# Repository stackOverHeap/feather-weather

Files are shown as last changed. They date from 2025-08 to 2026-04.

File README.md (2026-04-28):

# Feather-Weather
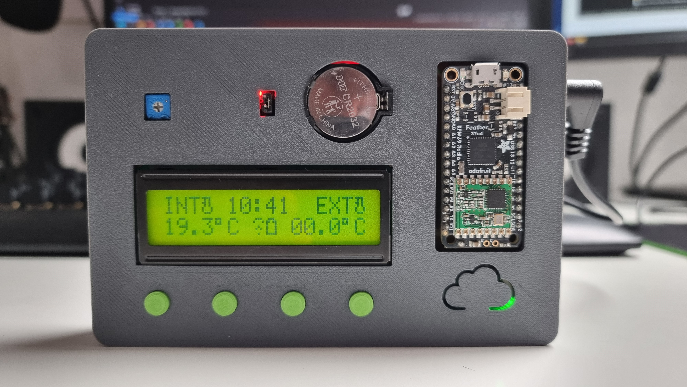
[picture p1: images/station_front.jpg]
The main station

### Qu'est-ce ?
Ce dépot contient le code source d'une **station météorologique** réalisée avec le framework **Arduino**. Elle est divisée en deux unités, équipées chacune de la carte **Adafruit Feather 32u4** Radio, qui travaillent séparément pour fournir des données sur la température et l'humidité ambiante à l'intérieur et à l'extérieur de l'habitacle. La communication entre ces deux unités se fait avec le module **rfm69hcw** sur la fréquence 433 MHz, ce qui permet l'échange de données sur une longue distance.

### Fonctionnalités
- [x] affichage des informations grâce à un écran LCD (16 x 2)
- [x] persistance du comptage de l'heure après coupure de courant (DS3231 RTC)
- [x] affichage de la température et de l'humidité ambiante  (ATH20)
- [x] configuration de l'heure par interface graphique
- [x] navigation dans les menus grâce à quatre bouton poussoires
- [x] voyant indicateur de d'état de batterie et qualité de réception
- [ ] historique des températures (min et max)
- [ ] possibilité de consulter le voltage de la batterie à distance

### TODO
- [x] suppression de la dépendance JSON
- [ ] reduction de l'utilisation de l'i2c pour augmenter la fiabilité du capteur de température (trop de requêtes = surchauffe)
- [ ] suppression de l'utilisation des print-format, trop gourmands pour AVR

## Compilation & Usage
### 1. Cloner le repo git
```bash
git clone https://github.com/stackOverHeap/feather-weather.git
```
### 2. Compiler avec platformIO
```bash
pio run
```
### 3. Flasher sur un micro
flash du code s'éxecutant sur la station interne
```bash
pio run --target upload --environment feather32u4_STATION
```
flash du code s'éxecutant sur la station externe
```bash
pio run --target upload --environment feather32u4_MODULE
```
### 4. Verifier la connexion entre les dispositifs
Pour ceci, s'assurer que l'icone de connexion n'apparaît pas sur l'interface de l'appareil. Un certain temps peut être nécessaire avant la détection du signal.

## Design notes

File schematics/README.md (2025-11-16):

# Project schematics
Theses were made with **KiCad EDA**

## files

- ***station météo externe.zip*** is the main module. It is designed for inside use and display temperature and humidity informations on a LCD screen. It also holds the time and date thanks to the use of a RTC clock.

- ***station météo interne.zip*** is the external module. It is made to be used outside for measuring humidity and temperature data, that it then sends trough radio to the station. A NE555 time is designed to wake the card on 30 secoond interval to reduce power consumption, since it is powered from a single 3.7v ion cell.

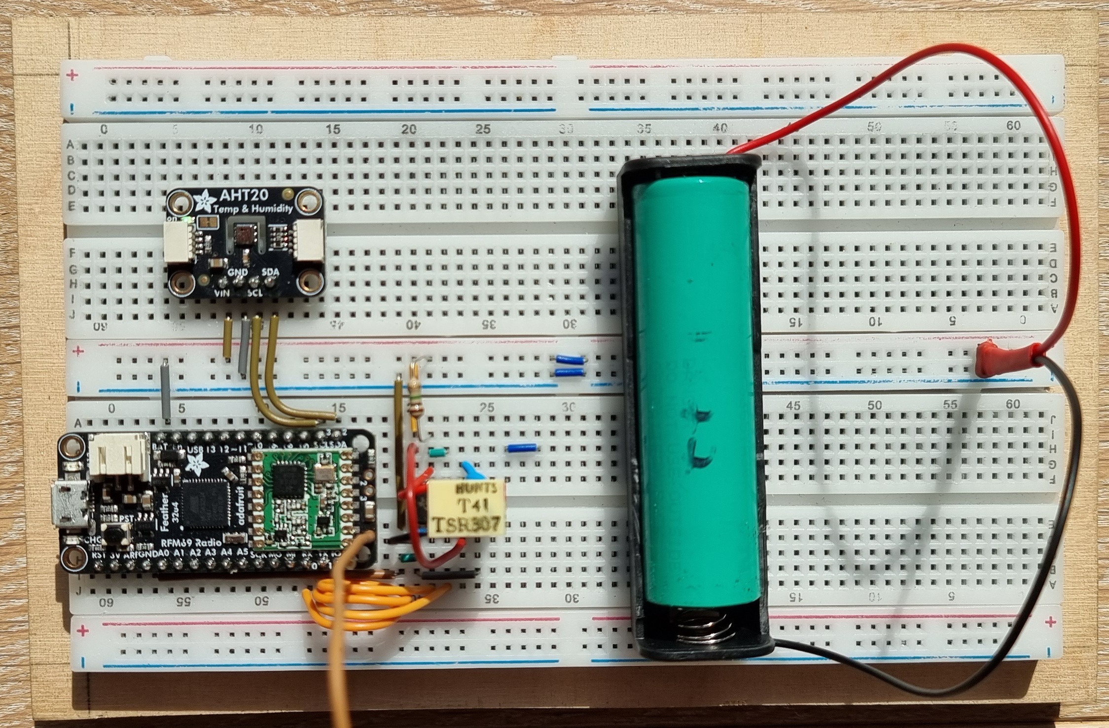
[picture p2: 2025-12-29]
images/module_front.jpg

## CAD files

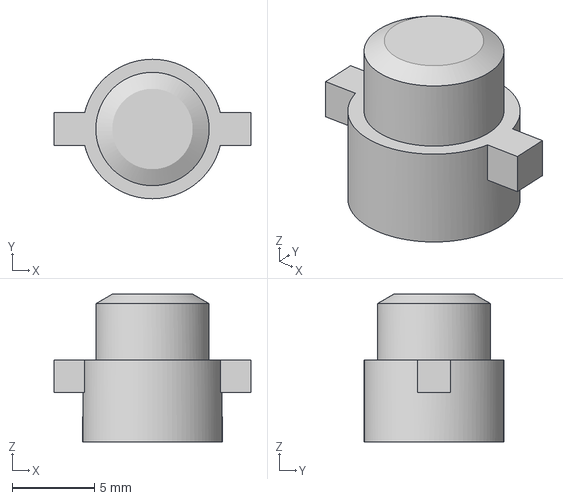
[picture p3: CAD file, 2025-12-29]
3D models/stls/push btn (x4).3mf
12.0 x 8.50 x 9.00 mm

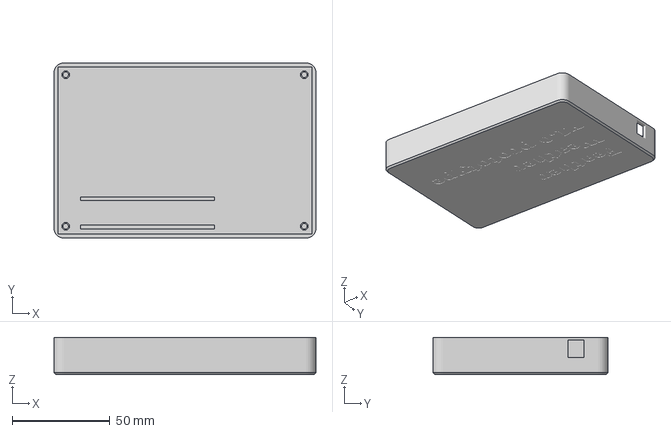
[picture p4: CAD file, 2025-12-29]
3D models/stls/back cover.3mf
134.0 x 89.5 x 19.0 mm

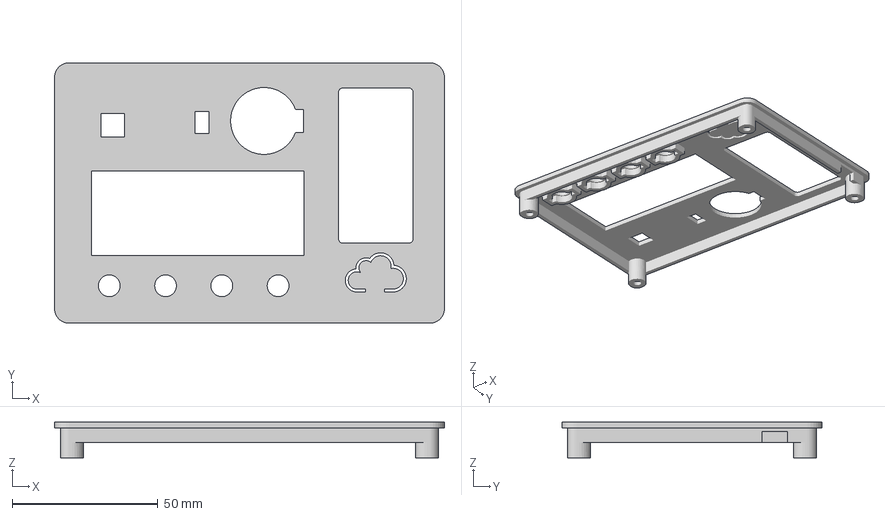
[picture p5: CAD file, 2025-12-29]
3D models/stls/front cover.3mf
134.0 x 89.5 x 12.3 mm

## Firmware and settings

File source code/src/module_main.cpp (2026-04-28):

#ifdef MODULE

#include <Arduino.h>
#include <RH_RF69.h>
#include <Adafruit_AHTX0.h>

#include <avr/wdt.h>
#include <avr/interrupt.h>
#include <avr/power.h>
#include <avr/sleep.h>

#include "radio.h"
#include "data_structure.hpp"

#define VBATPIN A9
#define WKPIN 0 // ne555 out
#define TRGPIN 1 // ne555 trig

#define SLEEP_TIME_S 64
#define SLEEP_CYCLE_COUNT (SLEEP_TIME_S / 8)

#define MIN_BATTERY_VOLTAGE 3.5f

RH_RF69 radio(RFM69_CS, RFM69_INT);
Adafruit_AHTX0 aht;

float vbat = 0;

void update_vbat()
{
  vbat = analogRead(VBATPIN);
  vbat *= 2;
  vbat *= 3.3;
  vbat /= 1024;
}

void wakeup_isr()
{
  digitalWrite(TRGPIN, HIGH);
}

ISR(WDT_vect) {}

void setup() {
  Serial.begin(115200);

  // Init radio
  radio.init();
  radio.setFrequency(RF69_FREQ);
  radio.setTxPower(15, true);  // Adjust based on range / power needs
  radio.setIdleMode(RH_RF69_OPMODE_MODE_SLEEP);

  // Init AHT20 sensor
  aht.begin();

#ifdef NE555
  pinMode(WKPIN, INPUT_PULLUP); 
  // Configure INT2 (D0) to trigger on falling edge
  attachInterrupt(digitalPinToInterrupt(WKPIN), wakeup_isr, FALLING);

  pinMode(TRGPIN, OUTPUT);
  digitalWrite(TRGPIN, HIGH); // prepare for ne555 wakeup pulse

  wdt_disable();
#endif

  power_usart0_disable();
  power_timer1_disable();
  power_timer2_disable();
  power_timer3_disable();
  power_usb_disable();
}

void loop() {  
#ifdef NE555
  EIMSK &= ~(1 << INT2);    // Disable INT2 interrupt
#endif
  // Wake up sensor, get data
  analogRead(VBATPIN); // dummy read
  update_vbat();

  sensors_event_t humidity, temp;
  aht.getEvent(&humidity, &temp);

  paquet_data_structure payload 
  {
    .temperature = temp.temperature,
    .humidity = humidity.relative_humidity,
    .battery_voltage = vbat
  };

  // Send data
  radio.send(reinterpret_cast<uint8_t*>(&payload), sizeof(paquet_data_structure));
  radio.waitPacketSent();

  // Put the radio into sleep mode

  // Disable ADC and other peripherals to save power
  power_adc_disable();
  power_twi_disable();
  power_spi_disable();
  power_timer0_disable();

#ifdef NE555
  // Now enter deep sleep
  digitalWrite(TRGPIN, LOW);
  delayMicroseconds(10);
  digitalWrite(TRGPIN, HIGH);
  EIFR = bit(INTF2); // clear pending INT2
  EIMSK |= (1 << INT2);    // Enable INT2 interrupt
#endif

  set_sleep_mode(SLEEP_MODE_PWR_DOWN);

#ifdef NE555
  sleep_mode();
#else
  int cycle_count = 0;

  sleep_enable();

  cli();
  wdt_reset();
  WDTCSR |= (1 << WDCE) | (1 << WDE);
  WDTCSR = (1 << WDIE) | (1 << WDP3) | (1 << WDP0); // interrupt only
  sei();

  while (cycle_count < SLEEP_CYCLE_COUNT)
  {
    sleep_cpu();
    cycle_count++;
  }

  cli();
  wdt_reset();
  WDTCSR |= (1 << WDCE) | (1 << WDE);
  WDTCSR = 0x00; // WDT fully off
  sei();

  sleep_disable();
#endif

  //  Re-enable ADC
  power_adc_enable();
  power_twi_enable();
  power_spi_enable();
  power_timer0_enable();
}

#endif

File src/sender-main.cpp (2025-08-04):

#ifdef SENDER

#include <Arduino.h>
#include <RH_RF69.h>
#include <ArduinoJson.h>
#include <Adafruit_AHTX0.h>
#include <Adafruit_SleepyDog.h>
#include <avr/wdt.h>
#include <avr/power.h>

#include "Radio-manager.h"

#define VBATPIN A9

RH_RF69 radio(RFM69_CS, RFM69_INT);
Adafruit_AHTX0 aht;
JsonDocument doc;

float vbat = 0;

void update_vbat()
{
  vbat = analogRead(VBATPIN);
  vbat *= 2;
  vbat *= 3.3;
  vbat /= 1024;
}

void setup() {
  Serial.begin(115200);

  // Init radio
  radio.init();
  radio.setFrequency(RF69_FREQ);
  radio.setTxPower(20, true);  // Adjust based on range / power needs
  radio.setIdleMode(RH_RF69_OPMODE_MODE_SLEEP);

  // Init AHT20 sensor
  aht.begin();
  Watchdog.enable(4000);
}

void loop() {
  // Re-enable ADC
  power_adc_enable();
  ADCSRA |= (1 << ADEN);

  // Wake up sensor, get data
  update_vbat();
  
  doc.clear();  // Clear previous JSON content
  
  if (vbat < 3.7) {
    doc["lowbat"] = true;
  } else {
    doc["lowbat"] = false;
  }

  sensors_event_t humidity, temp;
  aht.getEvent(&humidity, &temp);

  doc["temp"] = temp.temperature;
  doc["hum"] = humidity.relative_humidity;

  char payload[RH_RF69_MAX_MESSAGE_LEN];
  size_t len = serializeJson(doc, payload, sizeof(payload));

  // Send data
  radio.send((uint8_t*)payload, len);
  radio.waitPacketSent();

  // Put the radio into deep sleep
  radio.sleep();

  // Disable ADC and other peripherals to save power
  ADCSRA &= ~(1 << ADEN);
  power_adc_disable();
  power_spi_disable();
  power_timer1_disable();
  power_timer2_disable();
  power_twi_disable();

  // Optional: disable USB
  USBCON |= (1 << FRZCLK);
  PLLCSR &= ~(1 << PLLE);
  USBCON &= ~(1 << USBE);

  // Now enter deep sleep
  Watchdog.sleep(30000);
}


#endif

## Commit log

2025-08-13 removed temperature and humidity compensation
2025-08-15 removed temperature calibration, unable to acquire satisfaction
2025-11-16 repo structure simplification + added schematics
2025-11-22 removed ArduinoJson header
2025-11-22 removed ArduinoJson dependency
2025-11-22 added the current time in the callback args to facilitate access to time
2025-11-22 added a sensor poll limit to prevent overheating
2025-11-22 added a preliminary sensor poll on startup
2025-12-23 REM : removed useless Serial.print() statements
2025-12-29 add : 3d models and images
    [back cover.3mf, front cover.3mf, push btn (x4).3mf]
2025-12-29 mod : reduced i2c usage by limiting the screen refresh interval to 1 min
2026-04-25 fix : sensor
2026-04-28 add : event better power save with wtd wakeup
